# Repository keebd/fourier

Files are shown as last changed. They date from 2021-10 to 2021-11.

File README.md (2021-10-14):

Fourier Keyboard PCB
====================
This is a modified version of the original Fourier keyboard created by [nooges Danny](https://github.com/keebio/fourier) 

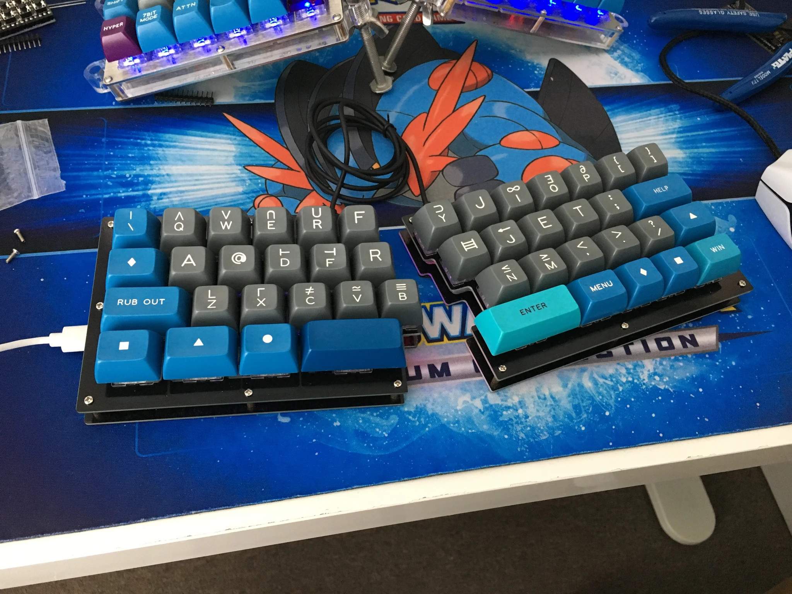
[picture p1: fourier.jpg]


Misc Info
---------
- Rev. 1.3 moved controllers to face forward to connect to a PC the same as all keyboards. Moved the LED pins to be unifrom on the inside of each half
- Rev. 1.2 added 1.25u/1u option at the inner two keys of each half, QMK support hasn't been added for those two new keys yet
- Keyboard Layout Editor: [Fourier 1.2 layout](http://www.keyboard-layout-editor.com/#/gists/ec52e429382754843fa2ddb02aecfc4a)

License
-------
These files are released under the MIT License.

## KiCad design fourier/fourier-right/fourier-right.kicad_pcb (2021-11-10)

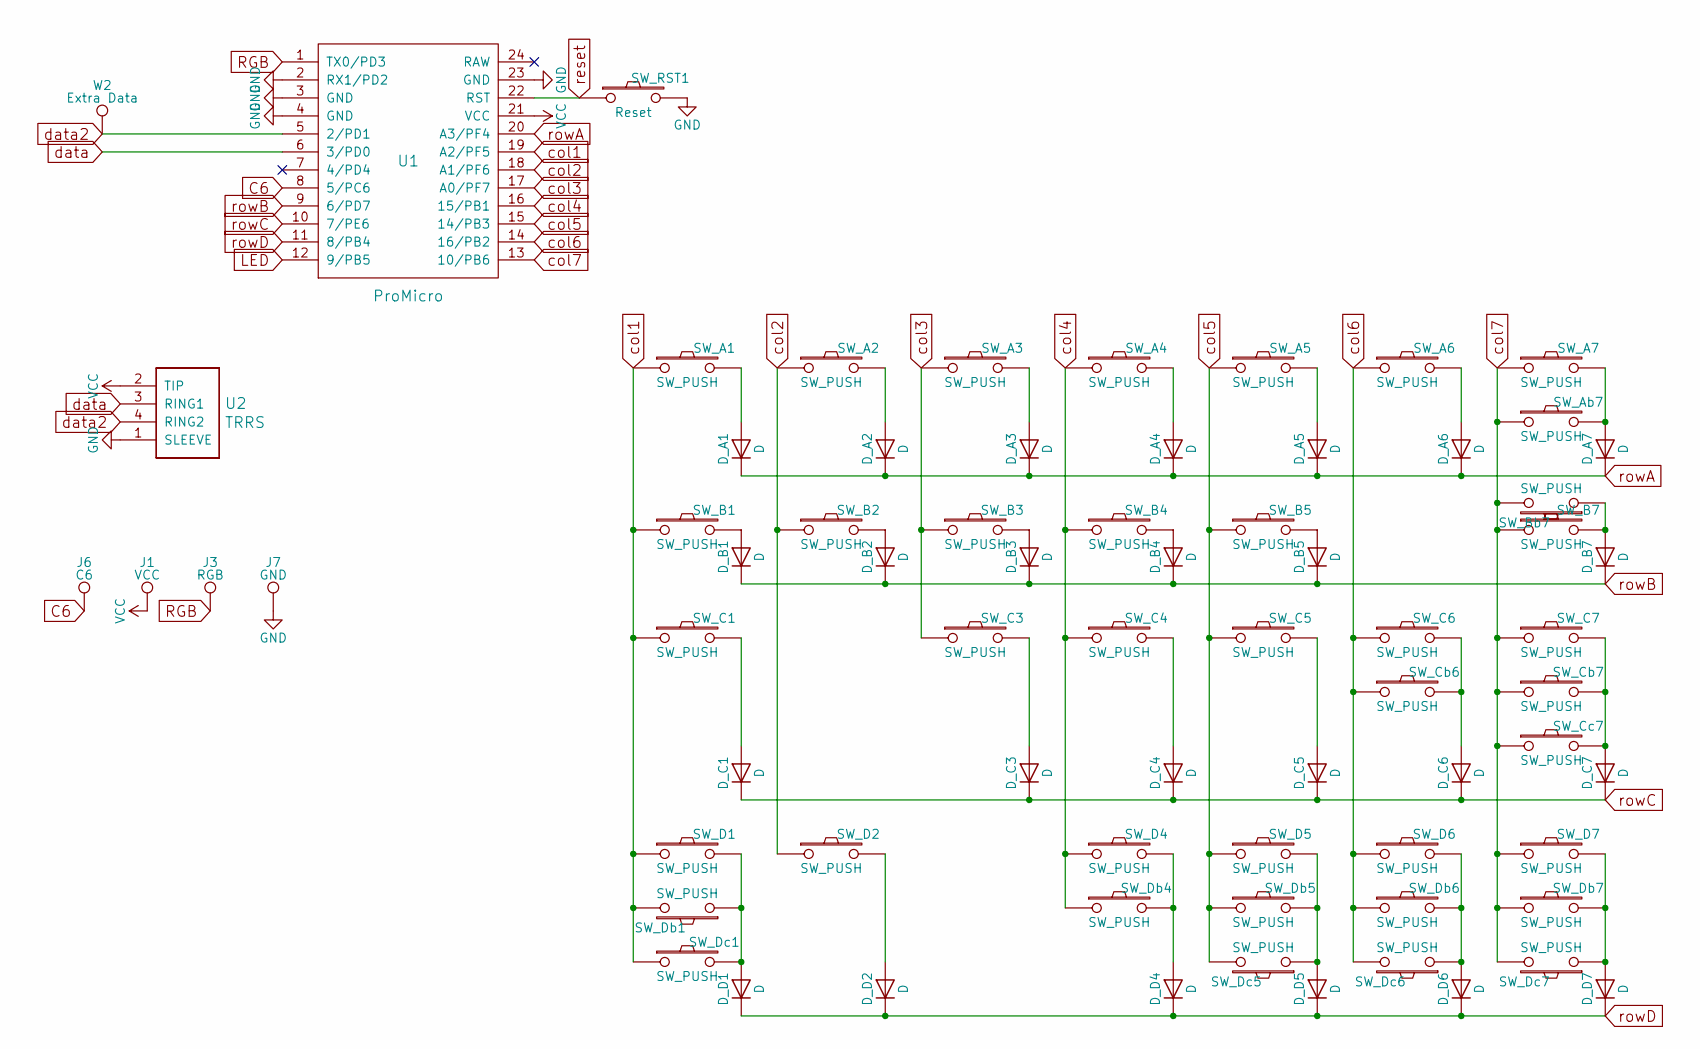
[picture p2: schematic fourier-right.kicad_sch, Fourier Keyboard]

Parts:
D_A1, D_A2, D_A3, D_A4, D_A5, D_A6, D_A7: D; Diode-Hybrid-Back
D_B1, D_B2, D_B3, D_B4, D_B5, D_B7: D; Diode-Hybrid-Back
D_C1, D_C3, D_C4, D_C5, D_C6, D_C7: D; Diode-Hybrid-Back
D_D1, D_D2, D_D4, D_D5, D_D6, D_D7: D; Diode-Hybrid-Back
J1: VCC; Single-Pad
J3: RGB; Single-Pad
J6: C6; Single-Pad
J7: GND; Single-Pad
SW_A1, SW_A2, SW_A3, SW_A4, SW_A5, SW_A6, SW_A7: SW_PUSH; MX-1U-NoLED
SW_Ab7: SW_PUSH; MX-2U-NoLED
SW_B1, SW_B2, SW_B3, SW_B4, SW_B5: SW_PUSH; MX-1U-NoLED
SW_B7: SW_PUSH; MX-1.75U-NoLED
SW_Bb7: SW_PUSH; MX-1.25U-NoLED
SW_C1, SW_C3, SW_C4, SW_C5, SW_C6: SW_PUSH; MX-1U-NoLED
SW_C7: SW_PUSH; MX-1.25U-NoLED
SW_Cb6: SW_PUSH; MX-1.25U-NoLED
SW_Cb7: SW_PUSH; MX-1U-NoLED
SW_Cc7: SW_PUSH; MX-2.25U-NoLED
SW_D1: SW_PUSH; MX-2.25U-ReversedStabilizers-NoLED
SW_D2, SW_D5, SW_D7: SW_PUSH; MX-1U-NoLED
SW_D4, SW_D6: SW_PUSH; MX-1.25U-NoLED
SW_Db1: SW_PUSH; MX-2.75U-ReversedStabilizers-NoLED
SW_Db4, SW_Db6: SW_PUSH; MX-1U-NoLED
SW_Db5, SW_Db7: SW_PUSH; MX-1.25U-NoLED
SW_Dc1: SW_PUSH; MX-1.25U-NoLED
SW_Dc5, SW_Dc7: SW_PUSH; MX-1.5U-NoLED
SW_Dc6: SW_PUSH; MX-1U-NoLED
SW_RST1: Reset; SW_Tactile_SPST_Angled_MJTP1117
U1: ProMicro; ArduinoProMicro-ZigZag
U2: TRRS; TRRS-PJ-320A
W2: Extra Data; Single-Pad

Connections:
C6: J6.1, U1.8 (5/PC6)
GND: J7.1, SW_RST1.2, U1.2 (RX1/PD2), U1.3 (GND), U1.4 (GND), U1.23 (GND), U2.1 (SLEEVE)
LED: U1.12 (9/PB5)
unnamed: D_A1.2 (A), SW_A1.2
unnamed: D_A2.2 (A), SW_A2.2
unnamed: D_A3.2 (A), SW_A3.2
unnamed: D_A4.2 (A), SW_A4.2
unnamed: D_A5.2 (A), SW_A5.2
unnamed: D_A6.2 (A), SW_A6.2
unnamed: D_A7.2 (A), SW_A7.2, SW_Ab7.2
unnamed: D_B1.2 (A), SW_B1.2
unnamed: D_B2.2 (A), SW_B2.2
unnamed: D_B3.2 (A), SW_B3.2
unnamed: D_B4.2 (A), SW_B4.2
unnamed: D_B5.2 (A), SW_B5.2
unnamed: D_B7.2 (A), SW_B7.2, SW_Bb7.1
unnamed: D_C1.2 (A), SW_C1.2
unnamed: D_C3.2 (A), SW_C3.2
unnamed: D_C4.2 (A), SW_C4.2
unnamed: D_C5.2 (A), SW_C5.2
unnamed: D_C6.2 (A), SW_C6.2, SW_Cb6.2
unnamed: D_C7.2 (A), SW_C7.2, SW_Cb7.2, SW_Cc7.2
unnamed: D_D1.2 (A), SW_D1.2, SW_Db1.1, SW_Dc1.2
unnamed: D_D2.2 (A), SW_D2.2
unnamed: D_D4.2 (A), SW_D4.2, SW_Db4.2
unnamed: D_D5.2 (A), SW_D5.2, SW_Db5.2, SW_Dc5.1
unnamed: D_D6.2 (A), SW_D6.2, SW_Db6.2, SW_Dc6.1
unnamed: D_D7.2 (A), SW_D7.2, SW_Db7.2, SW_Dc7.1
RGB: J3.1, U1.1 (TX0/PD3)
VCC: J1.1, U1.21 (VCC), U2.2 (TIP)
col1: SW_A1.1, SW_B1.1, SW_C1.1, SW_D1.1, SW_Db1.2, SW_Dc1.1, U1.19 (A2/PF5)
col2: SW_A2.1, SW_B2.1, SW_D2.1, U1.18 (A1/PF6)
col3: SW_A3.1, SW_B3.1, SW_C3.1, U1.17 (A0/PF7)
col4: SW_A4.1, SW_B4.1, SW_C4.1, SW_D4.1, SW_Db4.1, U1.16 (15/PB1)
col5: SW_A5.1, SW_B5.1, SW_C5.1, SW_D5.1, SW_Db5.1, SW_Dc5.2, U1.15 (14/PB3)
col6: SW_A6.1, SW_C6.1, SW_Cb6.1, SW_D6.1, SW_Db6.1, SW_Dc6.2, U1.14 (16/PB2)
col7: SW_A7.1, SW_Ab7.1, SW_B7.1, SW_Bb7.2, SW_C7.1, SW_Cb7.1, SW_Cc7.1, SW_D7.1, SW_Db7.1, SW_Dc7.2, U1.13 (10/PB6)
data: U1.6 (3/PD0), U2.3 (RING1)
data2: U1.5 (2/PD1), U2.4 (RING2), W2.1
reset: SW_RST1.1, U1.22 (RST)
rowA: D_A1.1 (K), D_A2.1 (K), D_A3.1 (K), D_A4.1 (K), D_A5.1 (K), D_A6.1 (K), D_A7.1 (K), U1.20 (A3/PF4)
rowB: D_B1.1 (K), D_B2.1 (K), D_B3.1 (K), D_B4.1 (K), D_B5.1 (K), D_B7.1 (K), U1.9 (6/PD7)
rowC: D_C1.1 (K), D_C3.1 (K), D_C4.1 (K), D_C5.1 (K), D_C6.1 (K), D_C7.1 (K), U1.10 (7/PE6)
rowD: D_D1.1 (K), D_D2.1 (K), D_D4.1 (K), D_D5.1 (K), D_D6.1 (K), D_D7.1 (K), U1.11 (8/PB4)

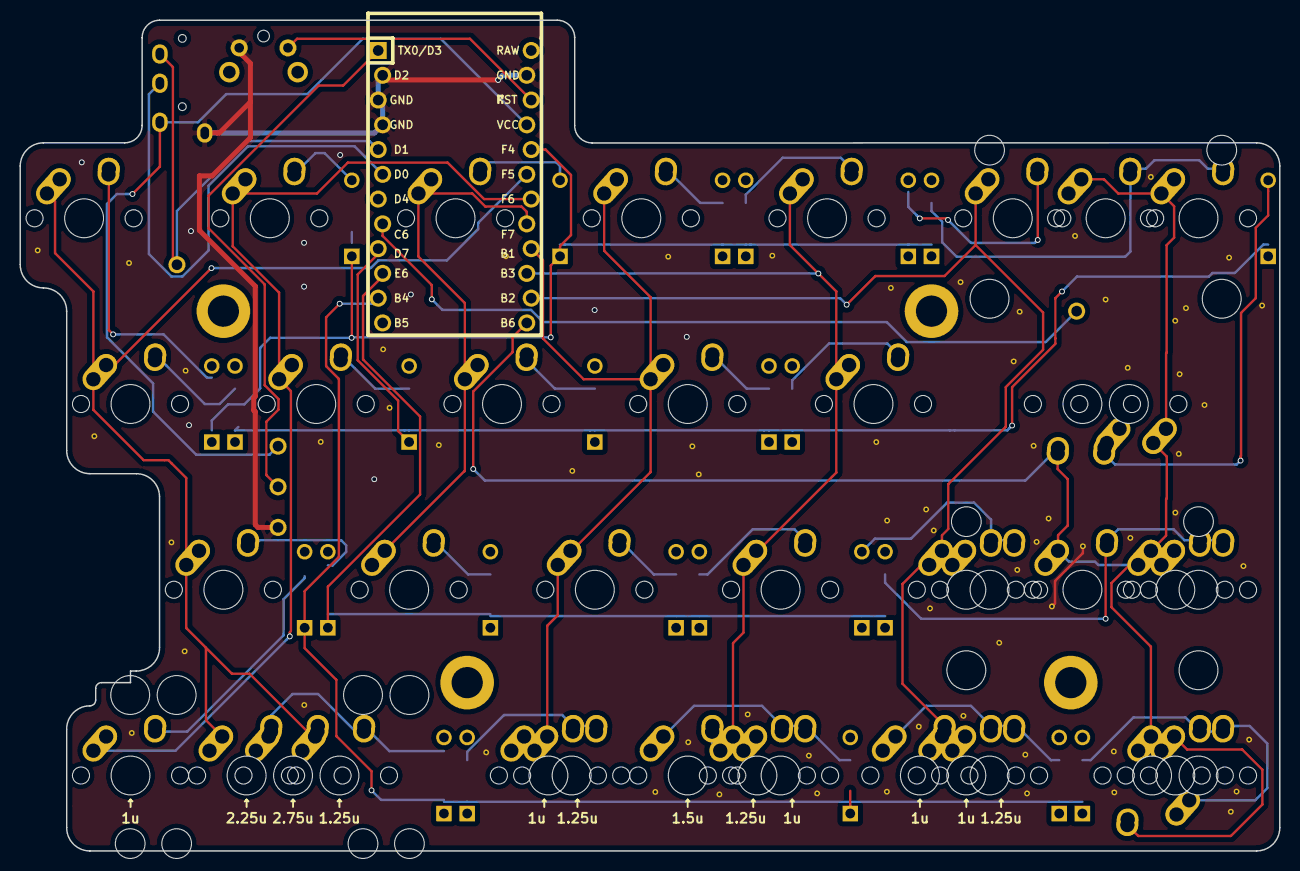
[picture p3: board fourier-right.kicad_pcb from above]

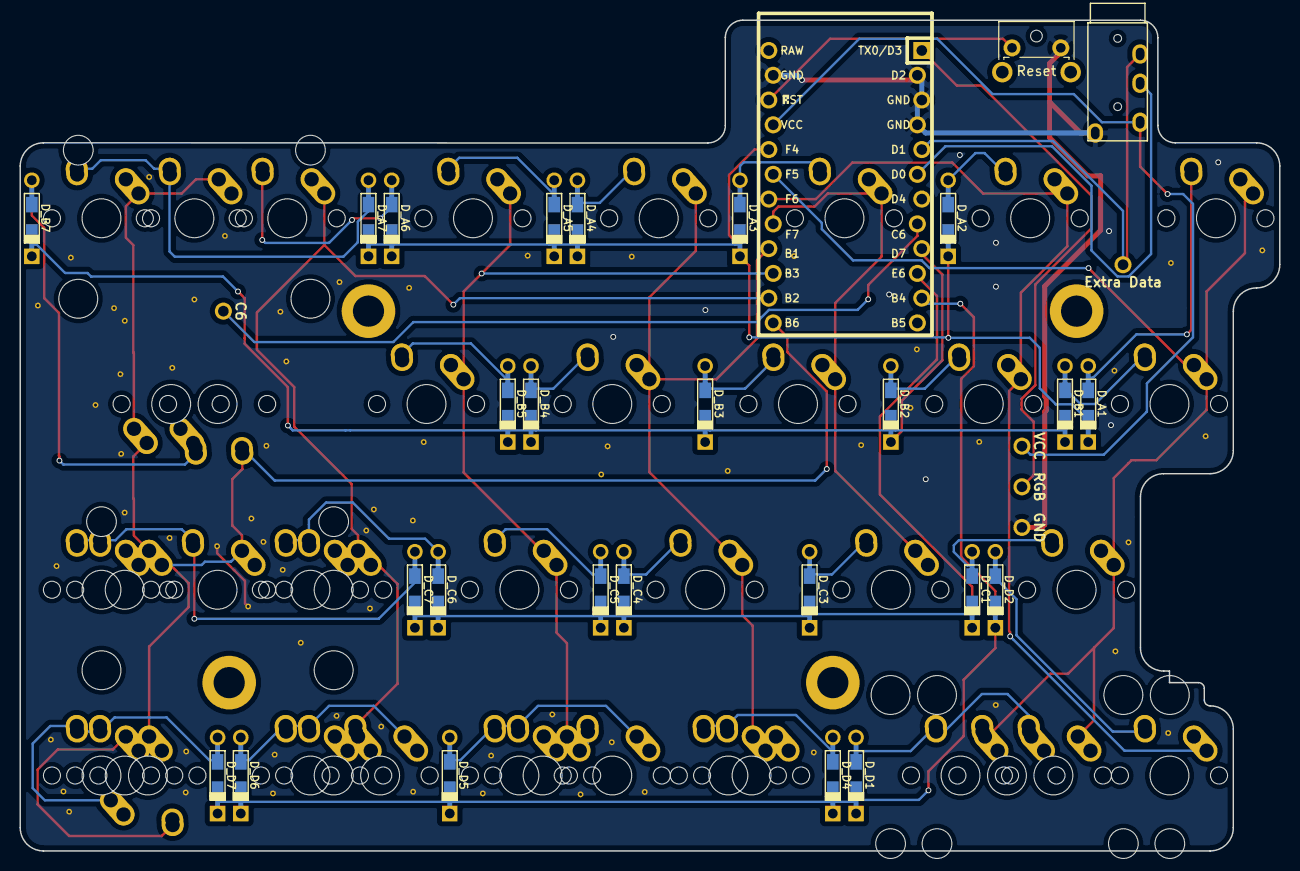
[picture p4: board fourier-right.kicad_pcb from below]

Board: 2 copper layers, 129.2 x 85.2 mm, 72 parts (2 on the bottom side), 43 nets.

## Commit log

2021-10-14 face controller forward and move LED breakout ports to unifrom position
    [fourier-left-bottom.kicad_pcb, fourier-left.kicad_pcb, fourier-right.kicad_pcb]
2021-10-14 fixed connections and ran DRC
    [fourier-left.kicad_pcb, fourier-right.kicad_pcb]
2021-11-07 Top height and center hole adjusment
    [fourier-left-bottom.kicad_pcb, fourier-left-top.kicad_pcb, fourier-right-bottom.kicad_pcb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]
2021-11-10 rotate left-top and update to KiCad 5.99
    [fourier-left-bottom.kicad_pcb, fourier-left-top.kicad_pcb, fourier-left.kicad_pcb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]
2021-11-10 removed center holes
    [fourier-left-top.kicad_pcb]
2021-11-10 rotate right top to correct orientation and upgraded to KiCad 5.99
    [fourier-right-bottom.kicad_pcb, fourier-right-top.kicad_pcb, fourier-right.kicad_pcb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]
2021-12-02 remove old board images
